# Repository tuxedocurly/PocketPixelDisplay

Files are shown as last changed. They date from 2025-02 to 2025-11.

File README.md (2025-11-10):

# Pocket Pixel Display - A portable, hackable LED Display

Welcome to the Pocket Pixel Display! I created this project to give me a customizable LED matrix platform to perform a wide variety of tasks. Use the display for product photography, show important notifications on the go, or load up WLED to add some animated ambiance to your workspace.

DSCF0302

Below, you'll find everything you need to build your own Pocket Pixel Display. If you prefer a video guide, check out my *[YouTube channel](https://www.youtube.com/@TuxedoMakes).*

## Buy me a coffee Support This Project (and Fuel Open Source!)

This project is a labor of love, built during my spare time. If you've found this project helpful, interesting, or just plain awesome, consider checking out [my shop](https://ko-fi.com/tuxedomakes/shop) where I sell PCBs and parts to make some of my projects, or buy me a coffee!

**Your support helps me:**

*   Dedicate more time to improve designs
*   Experiment with new features and ideas
*   Kickstart other open-source projects you might love

Even a small coffee-sized contribution goes a long way in fueling my passion for sharing my projects with you all. If you use the shop, you'll get a useful part for your next project, plus my eternal gratitude!

**Thank you for being awesome!**

---

## Table of Contents

- [Introduction](#introduction)
- [Materials & Tools](#materials--tools)
- [Hardware Assembly](#hardware-assembly)
  - [3D Printing & Case Preparation](#3d-printing--case-preparation)
  - [Battery & Power Setup](#battery--power-setup)
  - [LED Matrix Preparation](#led-matrix-preparation)
  - [Prepping the D1 Mini](#prepping-the-d1-mini)
  - [Wiring & Final Assembly](#wiring--final-assembly)
- [Software Setup](#software-setup)
  - [Installing WLED](#installing-wled)
  - [Installing the Custom Arduino Code (Gmail Notifications)](#installing-the-custom-arduino-code-gmail-notifications)
- [Customization Ideas](#customization-ideas)
- [License](#license)

---

## Introduction

The bill of materials (BOM) for this project is ~$20 - $40 depending on where you get your materials, and you'll need ~1 hour to assemble to project.

---

## Materials & Tools

### Components

- **8×8 LED Matrix** (WS2812B/NeoPixel) ([Amazon](https://amzn.to/4b0lBRX))
- **D1 Mini Microcontroller** ([Amazon](https://amzn.to/4gIIWJ6))
- **LiPo Battery** (1000mAh or better) ([Amazon](https://amzn.to/4kdQvL9))
- **Charge Controller with 5V Boost Board** ([Amazon](https://amzn.to/3EBV8yh))
- **On/Off Toggle Switch** ([Amazon](https://amzn.to/3EFhYF2))
- **JST Connector** (optional, for easy battery connection) ([Amazon](https://amzn.to/3EBzHND))
- **M2 Screws** ([Amazon](https://amzn.to/3EAxHp1))
- **Heat Set Inserts** ([Amazon](https://amzn.to/41gzCba))
- **Wires & Soldering Supplies** 
- **Double-Sided Tape** (for securing the battery) ([Amazon](https://amzn.to/4jXWT8S))
- **3D-Printed Case Parts** ([Maker World](https://makerworld.com/en/models/1095883#profileId-1090255))

### Tools

- 3D Printer (or access to one via a library/makerspace) ([Bambu Lab A1 Mini](https://amzn.to/42XF7ge))
- Soldering Iron & Solder ([Amazon](https://amzn.to/3COL2te))
- Multimeter ([Amazon](https://amzn.to/3Qmp3wV))
- Screwdriver (for M2 screws)
- Heat Shrink Tubing ([Amazon](https://amzn.to/4jWDYeJ))

components

---

## Hardware Assembly

### 3D Printing & Case Preparation

1. **Print the Case Parts:**  
   Use the linked 3D design files (or the STLs in this repo) to print all case components.
     - [Case Files on Maker World](https://makerworld.com/en/models/1095883#profileId-1090255)
  
disassembled_high_quality

3. **Install Heat Set Inserts:**  
   - In the **top case**, install 4 heat set inserts that will later secure the bottom case and top case together.
   - In the **bottom case**, install 2 heat set inserts to hold the charge controller and boost board.
   
heat_set_inserts

4. **Install Power Switch**
   - In  the **bottom case**, slide the power switch into place. It should snap into the slot with a bit of firm pressure.
  
power_switch

### Battery & Power Setup

1. **Prepare the Battery:**  
   - Fit your LiPo battery with a male JST connector, if not already present. This isn't required, but I highly recommend it. If you don't want to use JST connectors, you can use another appropriate connector, or solder the battery to the charge controller directly.
   - Solder a matching female JST connector onto the charge controller’s battery input terminals. Alternatively, solder the battery directly to the charge controller's battery input terminals. Note that the charge controller + boost converter used in this project is *always on*, so the variable voltage output terminals will be live whenever a power source is connected.

battery_jst

2. **Adjust Voltage:**  
   - Connect the battery to the charge controller via the JST connector.
   - Use a multimeter to measure the voltage at the output terminals of the charge controller.
   - Adjust the onboard resistor until you reach a steady 5 volts.

  voltage

3. **Solder Output Wires:**  
   - Solder wires to the positive and negative output terminals on the charge controller. These will power the LED matrix and other electronics.
  
power_connector

### LED Matrix Preparation

1. **Prepare the LED Matrix:**  
   - Use the supplied 3-wire connectors to attach wires to the LED matrix.  
   - **Important:** Ensure the wires are connected to the correct pads: positive, negative, and the **data in** pad (not data out).

  matrix_wires

### Prepping the D1 Mini

1. **Prepare the D1 Mini:**  
   - Grab your D1 Mini.

2. **Soldering Wires to the D1 Mini:**  
   - Solder a wire to the **5V** pin (power).
   - Solder a wire to the **GND** pin (ground).
   - Solder a wire to the **D4** pin, which will serve as the data out line to control the LED matrix.
   
d1_mini_wires

### Wiring & Final Assembly

1. **Connect All Wiring:**  
   - Refer to the wiring diagram below to connect the battery, charge controller, LED matrix, power switch, and D1 Mini.
   - Make sure all solder joints are secure and insulated with heat shrink tubing where necessary.

  circuit_image (1)

2. **Final Assembly:**  
   - Once all wiring is complete, connect the battery.
   - Screw the back of the case together using M2 screws to secure the entire assembly.
   - Install the 3D printed led grid holder, diffuser, and case cover

  assembly_done
  final_assembly_2

---

## Software Setup

### Installing WLED

1. **Overview:**  
   WLED is a powerful tool that lets you run a variety of cool animations on your LED matrix.

2. **Installation:**  
   - Download the WLED firmware and flash it onto your D1 Mini following the instructions in the [WLED documentation](https://github.com/Aircoookie/WLED).
   - Configure your WiFi settings as prompted.
   - Once flashed, your LED matrix is ready to display animations!

### Installing the Custom Arduino Code (Gmail Notifications)

1. **Overview:**  
   For a custom twist, I've written an Arduino sketch that displays a Gmail logo on your LED matrix whenever you receive a new email.

2. **Setup Instructions:**  
   - Open the Arduino IDE and download the arduino sketch from [GitHub](https://github.com/yourusername/yourrepository).
   - Open the provided Arduino sketch.
   - **Important:** Update the placeholder WiFi credentials with your own network details, as the code needs internet access to check your Gmail inbox. Update the email and password fields with your own information as well. If you use two factor authentication, you'll need to generate an application specific password for the password field.
   - Make sure the power switch on your display is **off** and connect the D1 Mini to your computer.
   - Select the correct board and port for your D1 Mini in the Arduino IDE.
   - Upload the sketch to your D1 Mini.

3. **Testing:**  
   - Once the code is uploaded, power cycle your device.
   - Send a test email to your Gmail account and watch for the Gmail logo to appear on your LED matrix!

---

## Customization Ideas

This project is designed to be a launchpad for your own creative implementations. Here are some ideas:
- **Custom Notifications:** Modify the Arduino sketch to display different icons or animations for various alerts (e.g., chat messages, calendar reminders, weather alerts).
- **Additional Controls:** Add buttons, encoders, or even a small screen to enhance interactivity, or turn the display into some sort of gaming device.
- **Advanced Animations:** Explore more complex WLED effects or integrate sensor data for dynamic displays.

---

## License

This project is open source and available under the [MIT License](LICENSE).

---

Happy building and happy hacking! If you have any questions or modifications, please feel free to open an issue or submit a pull request.

## ❤️ Support Me ❤️

If you liked this project, please consider checking out [my shop](https://ko-fi.com/tuxedomakes/shop) or [buying me a coffee ☕](https://ko-fi.com/tuxedomakes).

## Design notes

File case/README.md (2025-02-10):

3D printable case files.

You'll need to print the following quantities of each file:
- 1x - Bottom Case, Case Cover, Diffuser, LED Grid, Top Case
- 4x - LED Matrix Pin

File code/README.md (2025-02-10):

Sample code for various display functionality.

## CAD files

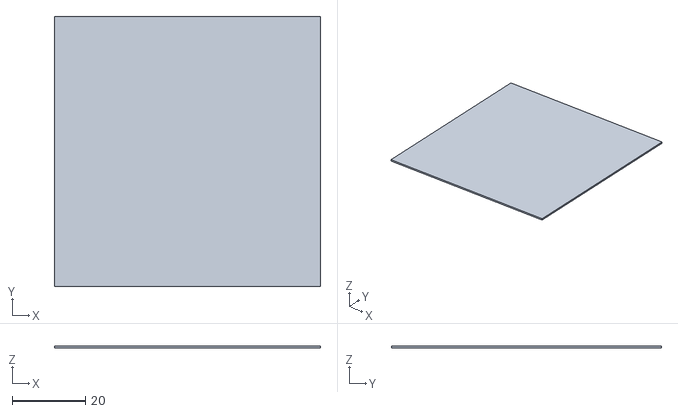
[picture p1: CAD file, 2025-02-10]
case/Diffuser.stl
72.8 x 73.9 x 0.6

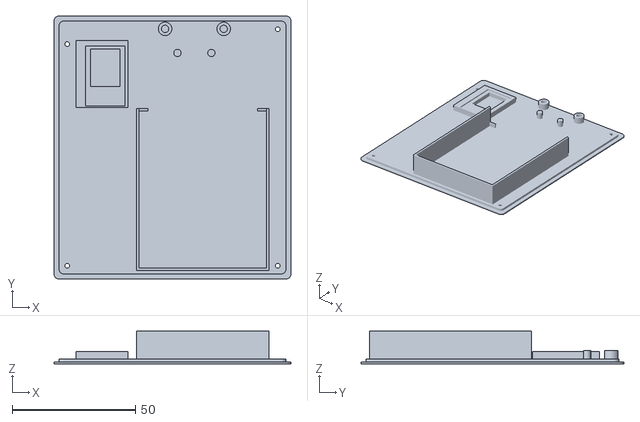
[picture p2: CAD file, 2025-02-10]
case/Bottom Case.stl
96.0 x 106.5 x 13.2

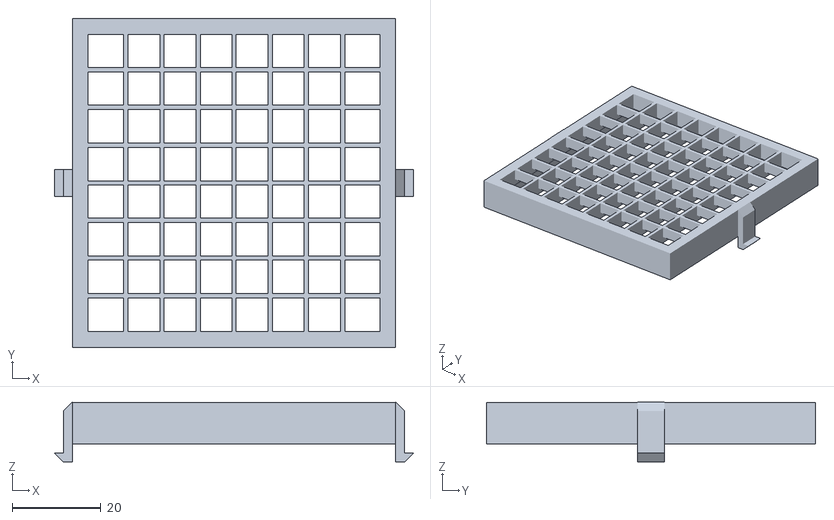
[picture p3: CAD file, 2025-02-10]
case/LED Grid.stl
80.8 x 73.9 x 13.5

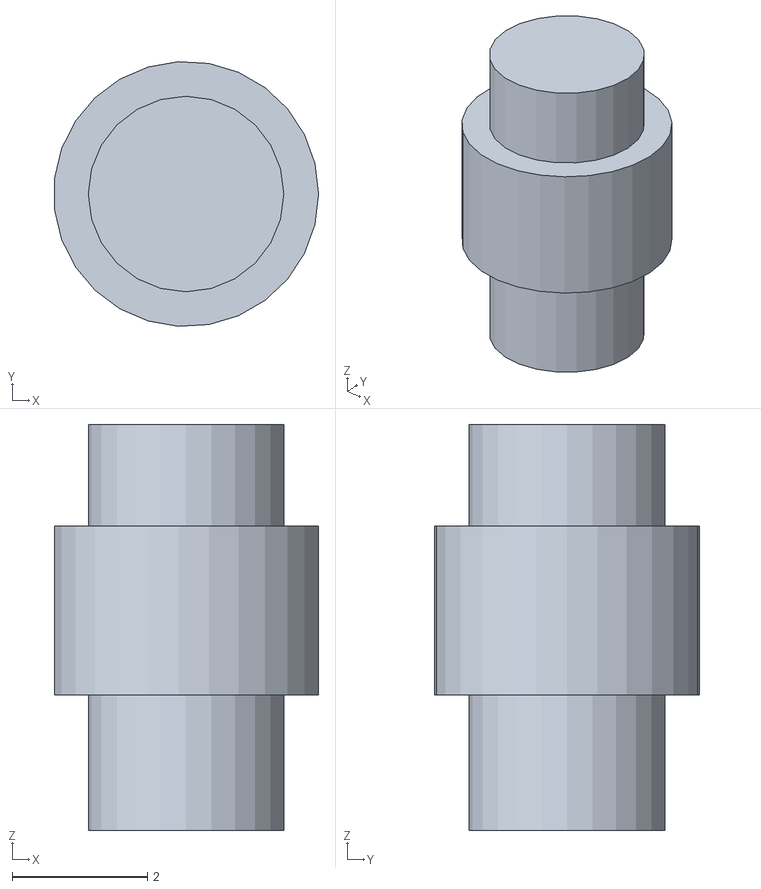
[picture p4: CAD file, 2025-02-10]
case/LED Matrix Pin.stl
3.90 x 3.91 x 6.00

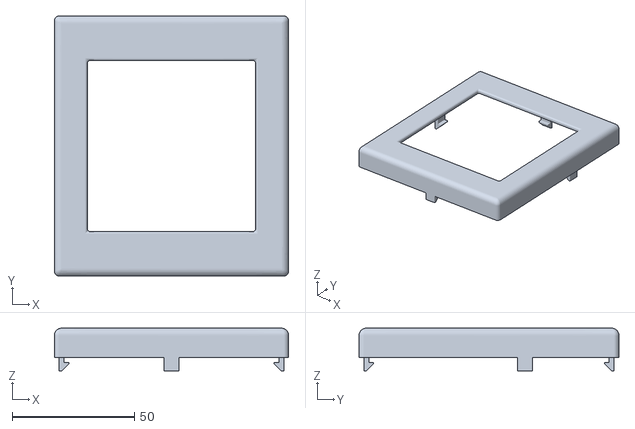
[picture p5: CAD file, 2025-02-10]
case/Case Cover.stl
96.0 x 106.5 x 17.5

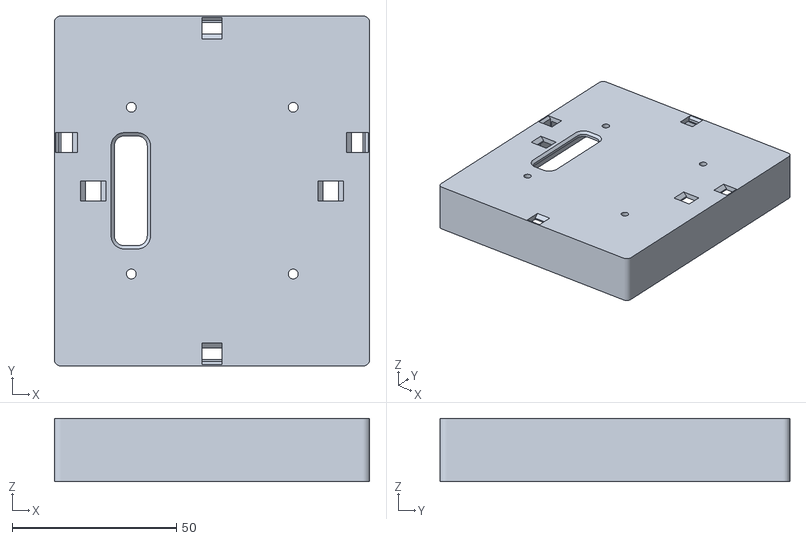
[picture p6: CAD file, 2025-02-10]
case/Top Case.stl
96.0 x 106.5 x 19.2

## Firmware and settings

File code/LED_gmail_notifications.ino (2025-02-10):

#include <Arduino.h>

// ------ WiFi Includes ------
#if defined(ESP8266)
#include <ESP8266WiFi.h>
#elif defined(ESP32)
#include <WiFi.h>
#endif

// ------ ESP_Mail_Client ------
#include <ESP_Mail_Client.h>

// ------ NeoPixel Includes ------
#include <Adafruit_NeoPixel.h>

// ---------- User Config ----------
// Replace with your actual WiFi and Gmail credentials.
#define WIFI_SSID       "WIFI_SSID_HERE"
#define WIFI_PASSWORD   "WIFI_PASSWORD_HERE"

// Gmail IMAP server settings
#define IMAP_HOST       "imap.gmail.com"
#define IMAP_PORT       993
#define GMAIL_ADDRESS   "EMAIL_ADDRESS_HERE"
#define GMAIL_PASSWORD  "GMAIL_APP_SPECIFIC_PASSWORD_HERE"

// ------ NeoPixel (WS2812B) Settings ------
#define LED_PIN   D4   // or GPIO2, etc. Adjust as needed
#define NUM_LEDS  64   // 8x8 matrix
Adafruit_NeoPixel strip(NUM_LEDS, LED_PIN, NEO_GRB + NEO_KHZ800);

// ------ Simple 8x8 "Gmail" icon (hex = 0xRRGGBB) ------
static uint32_t gmailIcon[NUM_LEDS] = {
  // Row 1
  0x990030, 0x990030, 0x000000, 0x000000, 0x000000, 0x000000, 0xFFC20E, 0xFFC20E,
  // Row 2
  0x990030, 0x990030, 0xED1C24, 0x000000, 0x000000, 0xED1C24, 0xFFC20E, 0xFFC20E,
  // Row 3
  0x990030, 0x990030, 0xED1C24, 0xED1C24, 0xED1C24, 0xED1C24, 0xFFC20E, 0xFFC20E,
  // Row 4
  0x4D6DF3, 0x990030, 0xED1C24, 0xED1C24, 0xED1C24, 0xED1C24, 0xFFC20E, 0x22B14C,
  // Row 5
  0x4D6DF3, 0x4D6DF3, 0xED1C24, 0xED1C24, 0xED1C24, 0xED1C24, 0x22B14C, 0x22B14C,
  // Row 6
  0x4D6DF3, 0x4D6DF3, 0x000000, 0xED1C24, 0xED1C24, 0x000000, 0x22B14C, 0x22B14C,
  // Row 7
  0x4D6DF3, 0x4D6DF3, 0x000000, 0x000000, 0x000000, 0x000000, 0x22B14C, 0x22B14C,
  // Row 8
  0x4D6DF3, 0x4D6DF3, 0x000000, 0x000000, 0x000000, 0x000000, 0x22B14C, 0x22B14C
};

// ------ IMAP objects ------
IMAPSession imap;         // the IMAP session
Session_Config config;    // login/connection parameters
IMAP_Data imap_data;      // internal IMAP data settings

// ------ Function Prototypes ------
void connectWiFi();
void showGmailIcon();
void clearMatrix();
void imapCallback(IMAP_Status status);

// ---------------------------------

void setup()
{
  Serial.begin(115200);
  delay(1000);

  connectWiFi();

  // NeoPixel init
  strip.begin();
  strip.show(); // turn off all LEDs

  // Enable debug output (0 = none, 1 = basic)
  imap.debug(1);

  // Set a callback so we can see status or do something after fetch
  imap.callback(imapCallback);

  // Configure mail session
  config.server.host_name   = IMAP_HOST;
  config.server.port        = IMAP_PORT;
  config.login.email        = GMAIL_ADDRESS;
  config.login.password     = GMAIL_PASSWORD;
  // If SSL/TLS verification fails, optionally disable it:
  // config.server.cert_verify = false;

  // Connect to Gmail IMAP
  if (!imap.connect(&config, &imap_data))
  {
    Serial.printf("Failed to connect: %s\n", imap.errorReason().c_str());
    return;
  }

  // If credentials are good, we should be authenticated
  if (imap.isAuthenticated())
    Serial.println("IMAP login successful.");
  else
    Serial.println("IMAP connected, but not authenticated.");

  // Select the "INBOX" so we can listen for new emails
  if (!imap.selectFolder("INBOX"))
  {
    Serial.println("Failed to select INBOX.");
    return;
  }

  // Now we are set to listen for changes in loop().
}

void loop()
{
  // Listen for mailbox changes (IDLE/NOOP).
  // Returns true if successfully listening, false if there's an error.
  if (!imap.listen()) {
    // If there's a connection error, you might reconnect or handle it here.
    return;
  }

  // Has the folder status changed? (e.g. new mail arrived)
  if (imap.folderChanged())
  {
    // We can see what changed
    SelectedFolderInfo folderInfo = imap.selectedFolder();

    if (folderInfo.pollingStatus().type == imap_polling_status_type_new_message)
    {
      Serial.println("==> New Email Arrived!");

      // Stop listening while we handle the new message
      imap.stopListen();

      // Optionally, read or fetch the message here. For now, just show icon:
      showGmailIcon();

      // Wait 10 seconds. Modify this to change how long the gMail icon is displayed
      delay(10000);

      // Clear the matrix to make the icon go away
      clearMatrix();

      // Re-listen for new mail
      imap.listen();
    }
  }
}

// Connect to WiFi
void connectWiFi()
{
  Serial.printf("Connecting to WiFi: %s\n", WIFI_SSID);
  WiFi.mode(WIFI_STA);
  WiFi.begin(WIFI_SSID, WIFI_PASSWORD);
  while (WiFi.status() != WL_CONNECTED)
  {
    delay(500);
    Serial.print(".");
  }
  Serial.printf("\nWiFi connected. IP: %s\n", WiFi.localIP().toString().c_str());
}

// Light up the 8x8 matrix with the Gmail icon
void showGmailIcon()
{
  for (int i = 0; i < NUM_LEDS; i++)
    strip.setPixelColor(i, gmailIcon[i]);

  strip.show();
}

// Clear the matrix (all off)
void clearMatrix()
{
  for (int i = 0; i < NUM_LEDS; i++)
    strip.setPixelColor(i, 0x000000);

  strip.show();
}

// Minimal callback just to see final statuses, if needed
void imapCallback(IMAP_Status status)
{
  Serial.println(status.info());

  // If reading/fetching was successful, we can optionally do more here.
  // For example, read the fetched messages, etc.
}

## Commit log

2025-02-10 Create LED_gmail_notifications.ino
    Add arduino code for the gmail notifier
2025-02-10 Create README.md
    Create folder to house the 3D printable case files.
2025-02-10 Add STL files for the case
    [Bottom Case.stl, Case Cover.stl, Diffuser.stl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]
2025-02-14 Update README.md
    Uploaded a corrected circuit diagram showing the placement of the power switch.
